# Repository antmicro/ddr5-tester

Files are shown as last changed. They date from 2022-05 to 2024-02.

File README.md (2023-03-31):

# Data Center RDIMM DDR5 Tester

Copyright (c) 2021-2023 [Antmicro](https://www.antmicro.com)



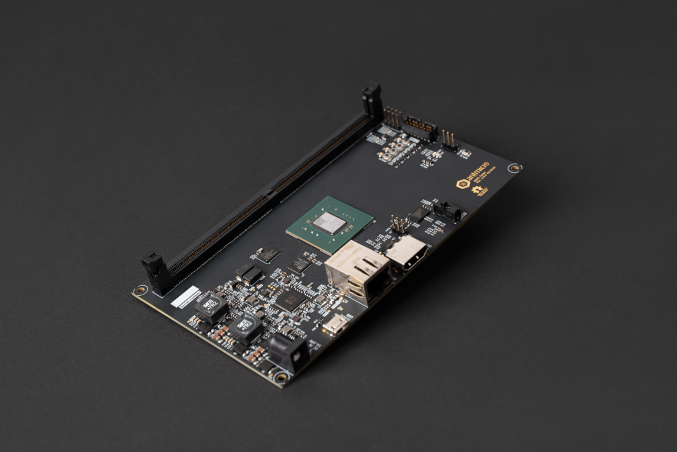
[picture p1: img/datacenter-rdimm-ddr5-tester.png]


## Overview

This project contains open hardware design files for an experimental platform built around Xilinx Kintex-7 FPGA.
The main purpose of this platform is to develop and customize RAM controllers supporting DIMM DDR5 RAM modules used in data centers.
The design files were prepared in KiCad.

## Project structure

The main directory contains KiCad PCB project files, a
LICENSE and README. The remaining files are stored in the following
directories:

-   `lib` - contains the component libraries
-   `img` - contains graphics for this README
-   `doc` - contains schematics and block diagrams

## Key Features

-   Kintex-7 FPGA - XC7K160T-2FBG676C
-   DDR5 DIMM connector
-   HDMI output connector
-   Ethernet RJ45 connector with 1GbE transciever
-   Micro USB debug connector with FT4232HQ FTDI USB controller
-   JTAG
-   microSD card slot
-   16 MBytes S25FL128S QSPI FLASH memory
-   S27KL0641 HyperRAM
-   External 7-12V power input
-   5 user LEDs
-   4 user buttons

## Block diagram

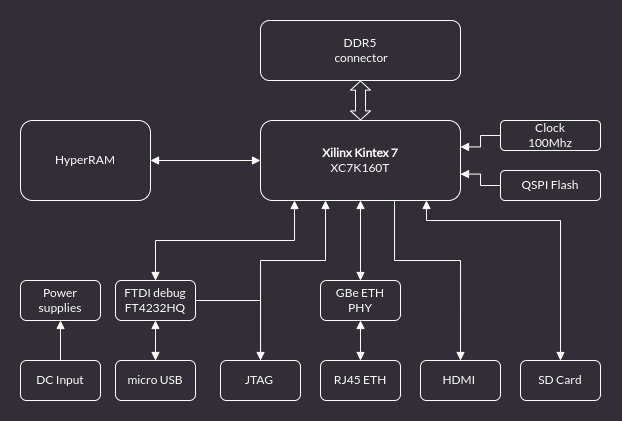
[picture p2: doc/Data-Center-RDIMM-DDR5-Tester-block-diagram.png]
Data Center RDIMM DDR5 Tester board diagram


## License

This project is published under the [Apache-2.0](LICENSE) license.

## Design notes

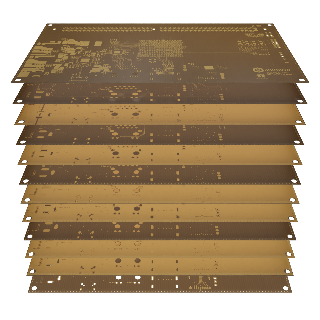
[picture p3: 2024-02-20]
assets/previews/layer1_thumbnail.webp

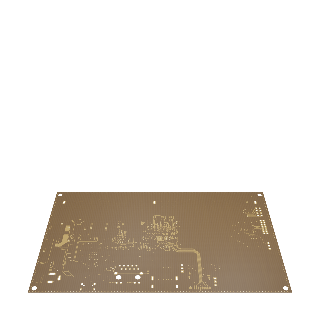
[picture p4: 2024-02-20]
assets/previews/layer12_thumbnail.png

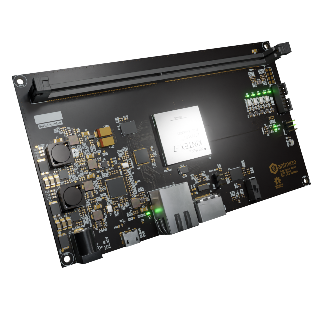
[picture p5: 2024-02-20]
assets/previews/leftT_thumbnail.png

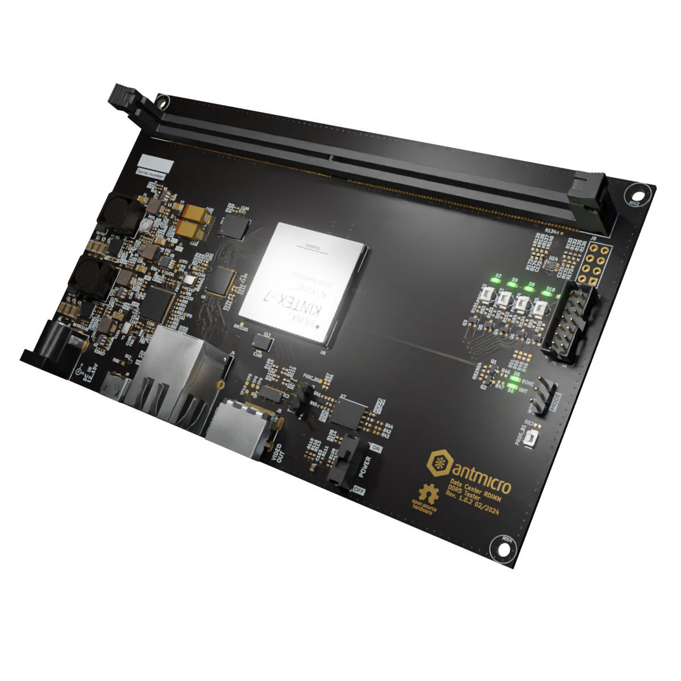
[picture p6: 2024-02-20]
assets/previews/rightT.webp

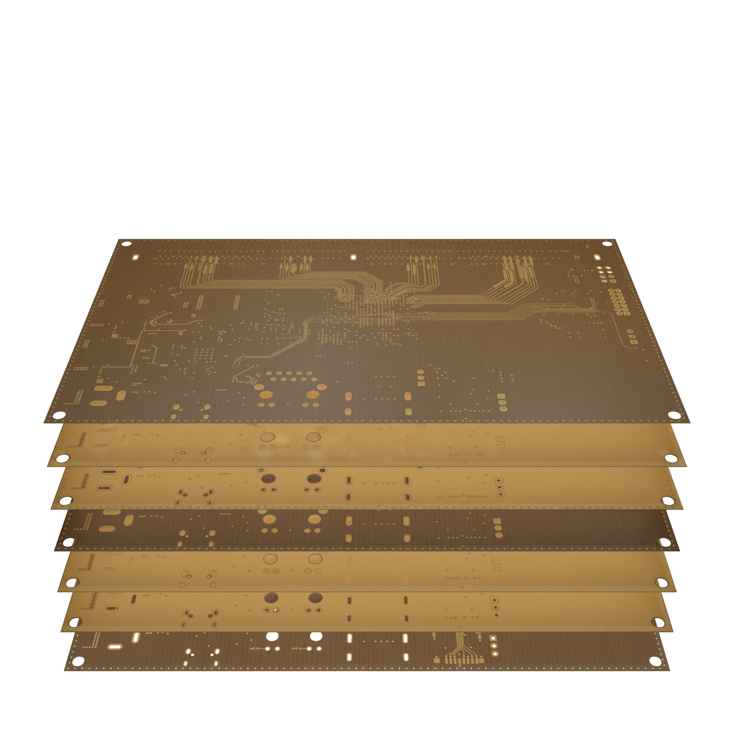
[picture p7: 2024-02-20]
assets/previews/layer6.png

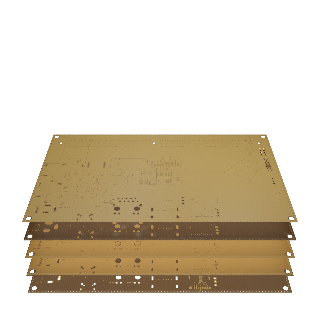
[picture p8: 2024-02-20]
assets/previews/layer8_thumbnail.png

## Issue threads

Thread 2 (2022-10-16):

Can't find Kintex-7 FPGA - XC7K100T-FBG686

StefanL312, 2022-10-16:
Hello,

Thank you for your work and for sharing this project.

I am currently working on my master thesis regarding DRAM row hammering and am interested in using your DDR5-tester.

I have trouble finding the XC7K100T-FBG686 FPGA.

Could you advise me on this matter. Would you have possibly meant the 160 variant instead?

I am looking forward to your reply.

Kind regards,
Stefan

pkatarzynski, 2022-12-07:
Hi Stefan - indeed there was a glitch in the MPN indicated in the README. I have already fixed that. The MPN for the FPGA should be XC7K160T-FBG676.  We are using XC7K160T-2FBG676C in the prototypes. The board can also be populated with 'FFG' version which is footprint-compatible.

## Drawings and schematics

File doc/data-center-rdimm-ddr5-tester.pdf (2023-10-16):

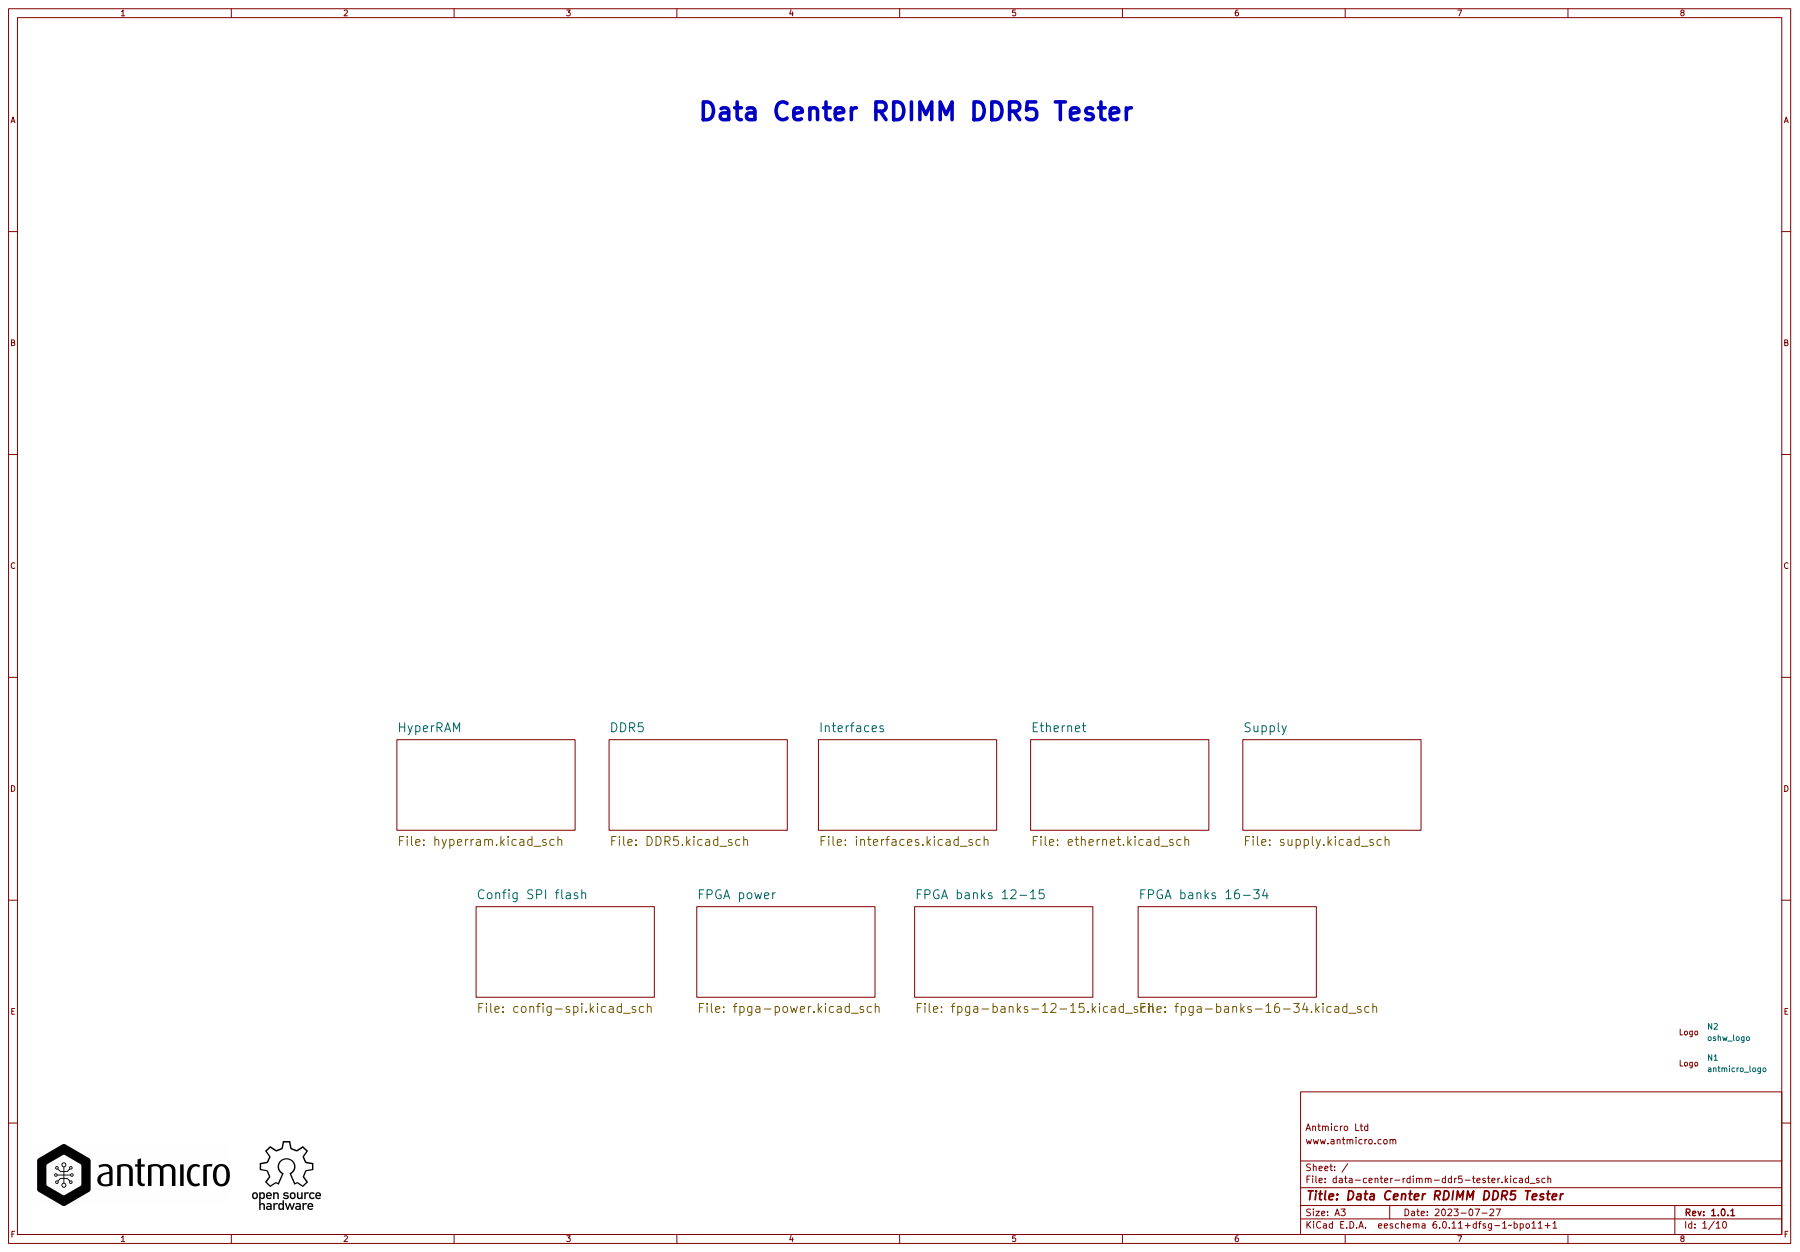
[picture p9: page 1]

Id: 1/10 Title: Data Center RDIMM DDR5 Tester File: data-center-rdimm-ddr5-tester.kicad_sch Sheet: / www.antmicro.com

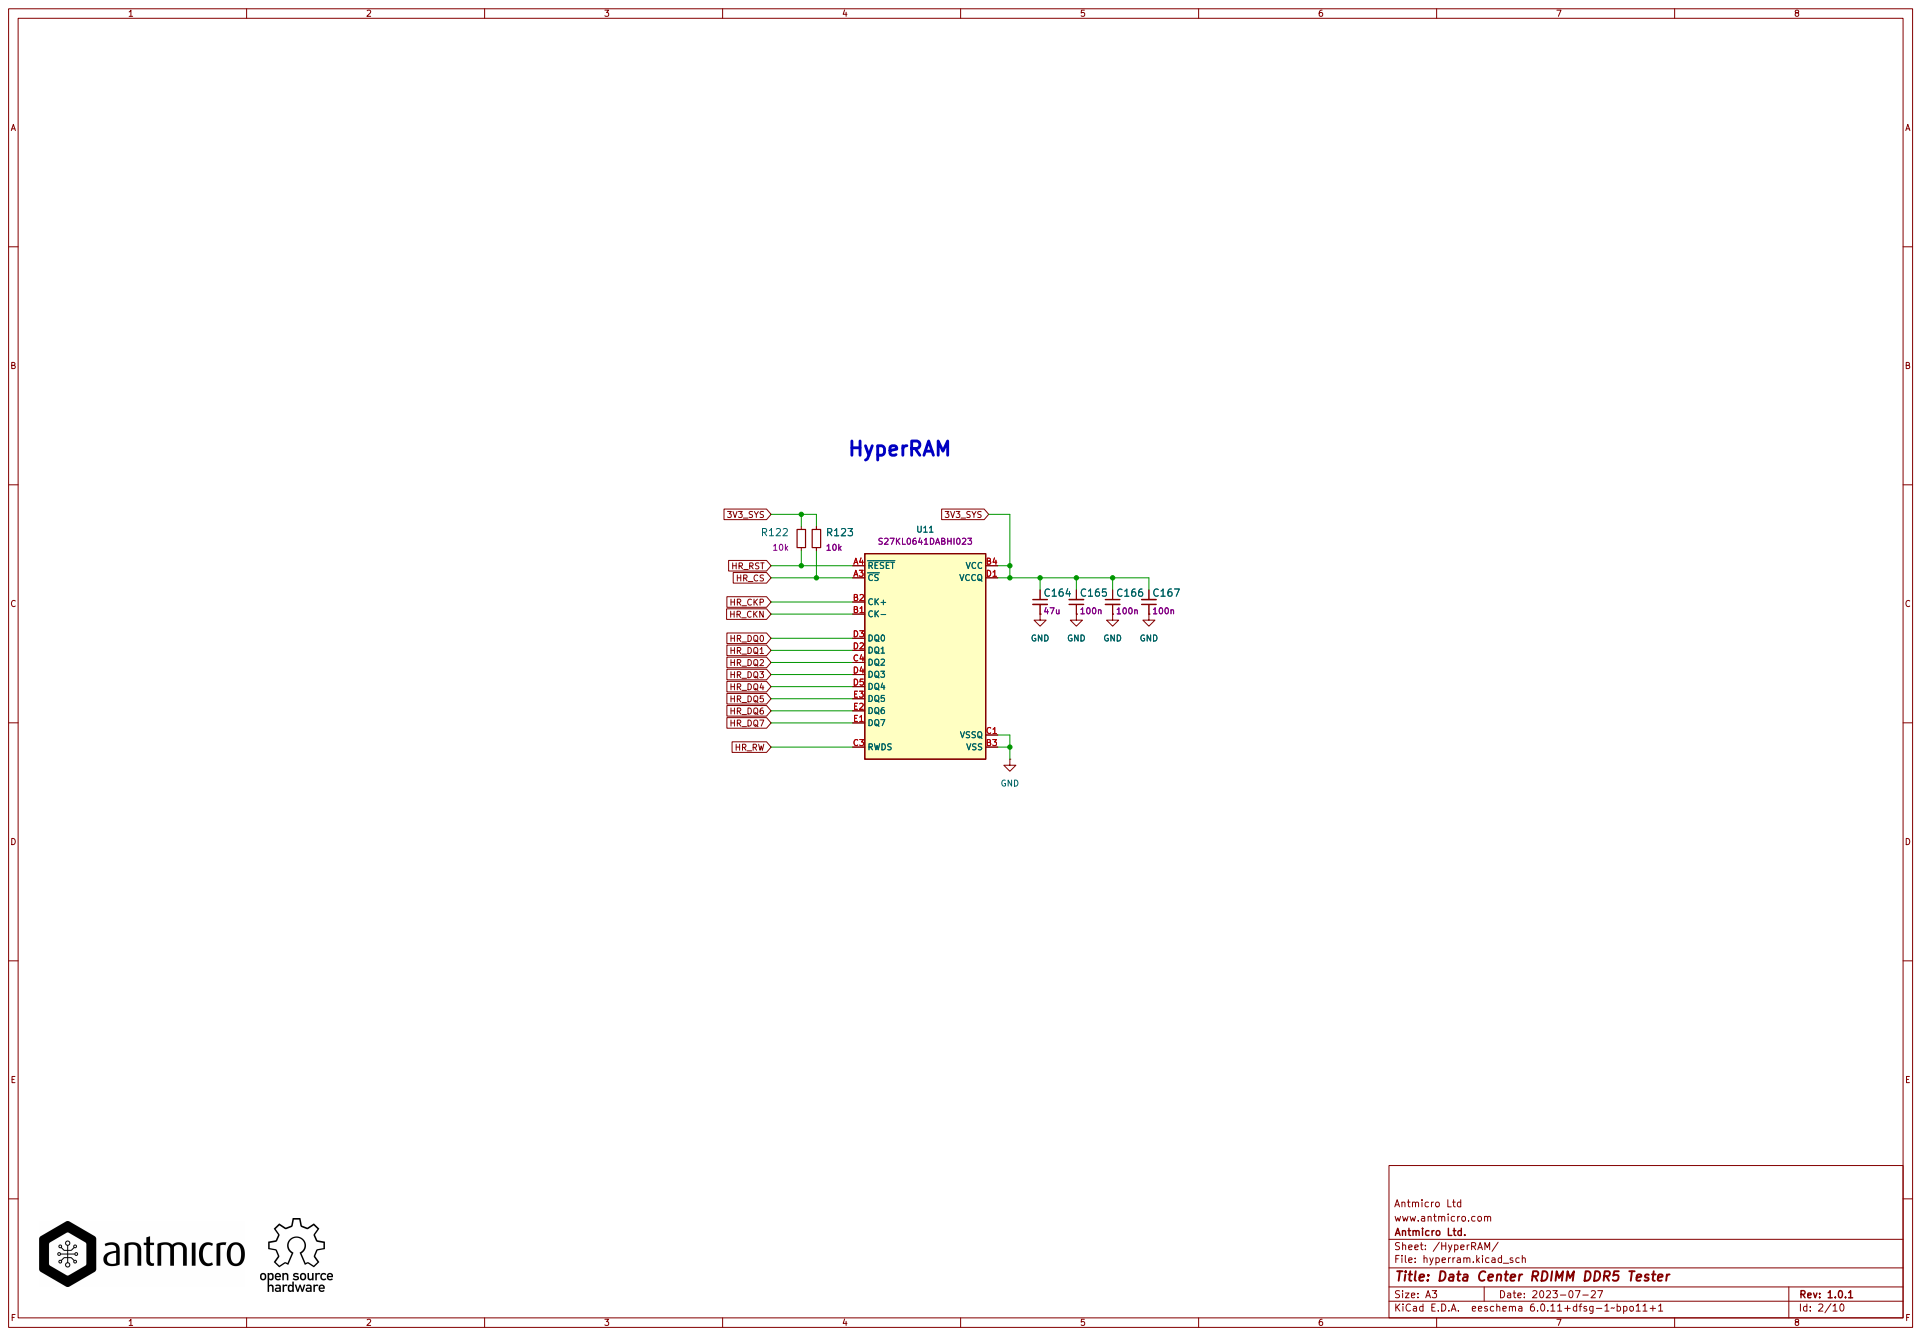
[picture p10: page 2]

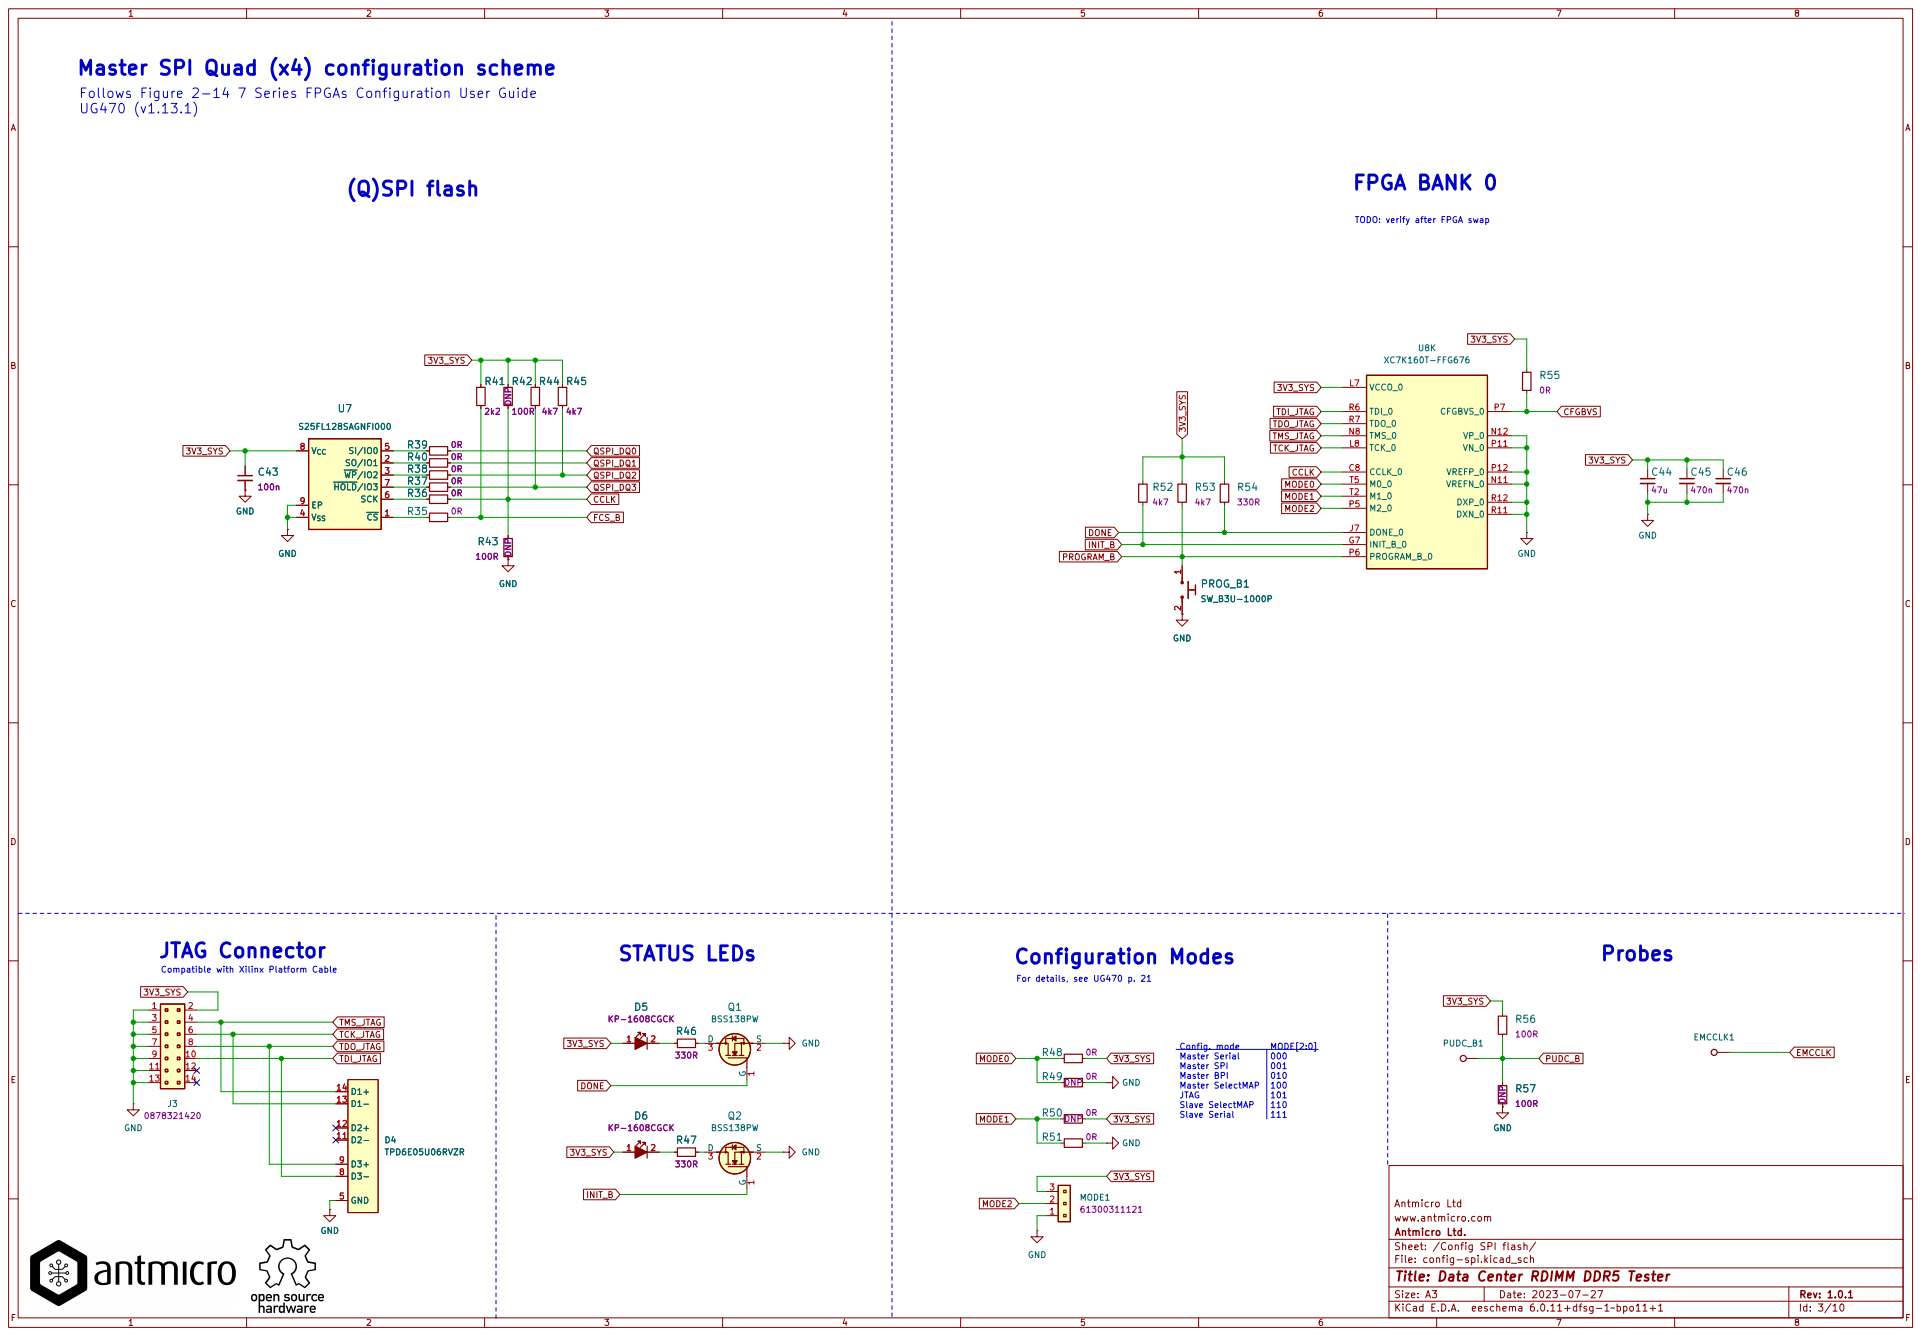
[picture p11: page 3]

Config. mode Master Serial Master SPI Master BPI Master SelectMAP

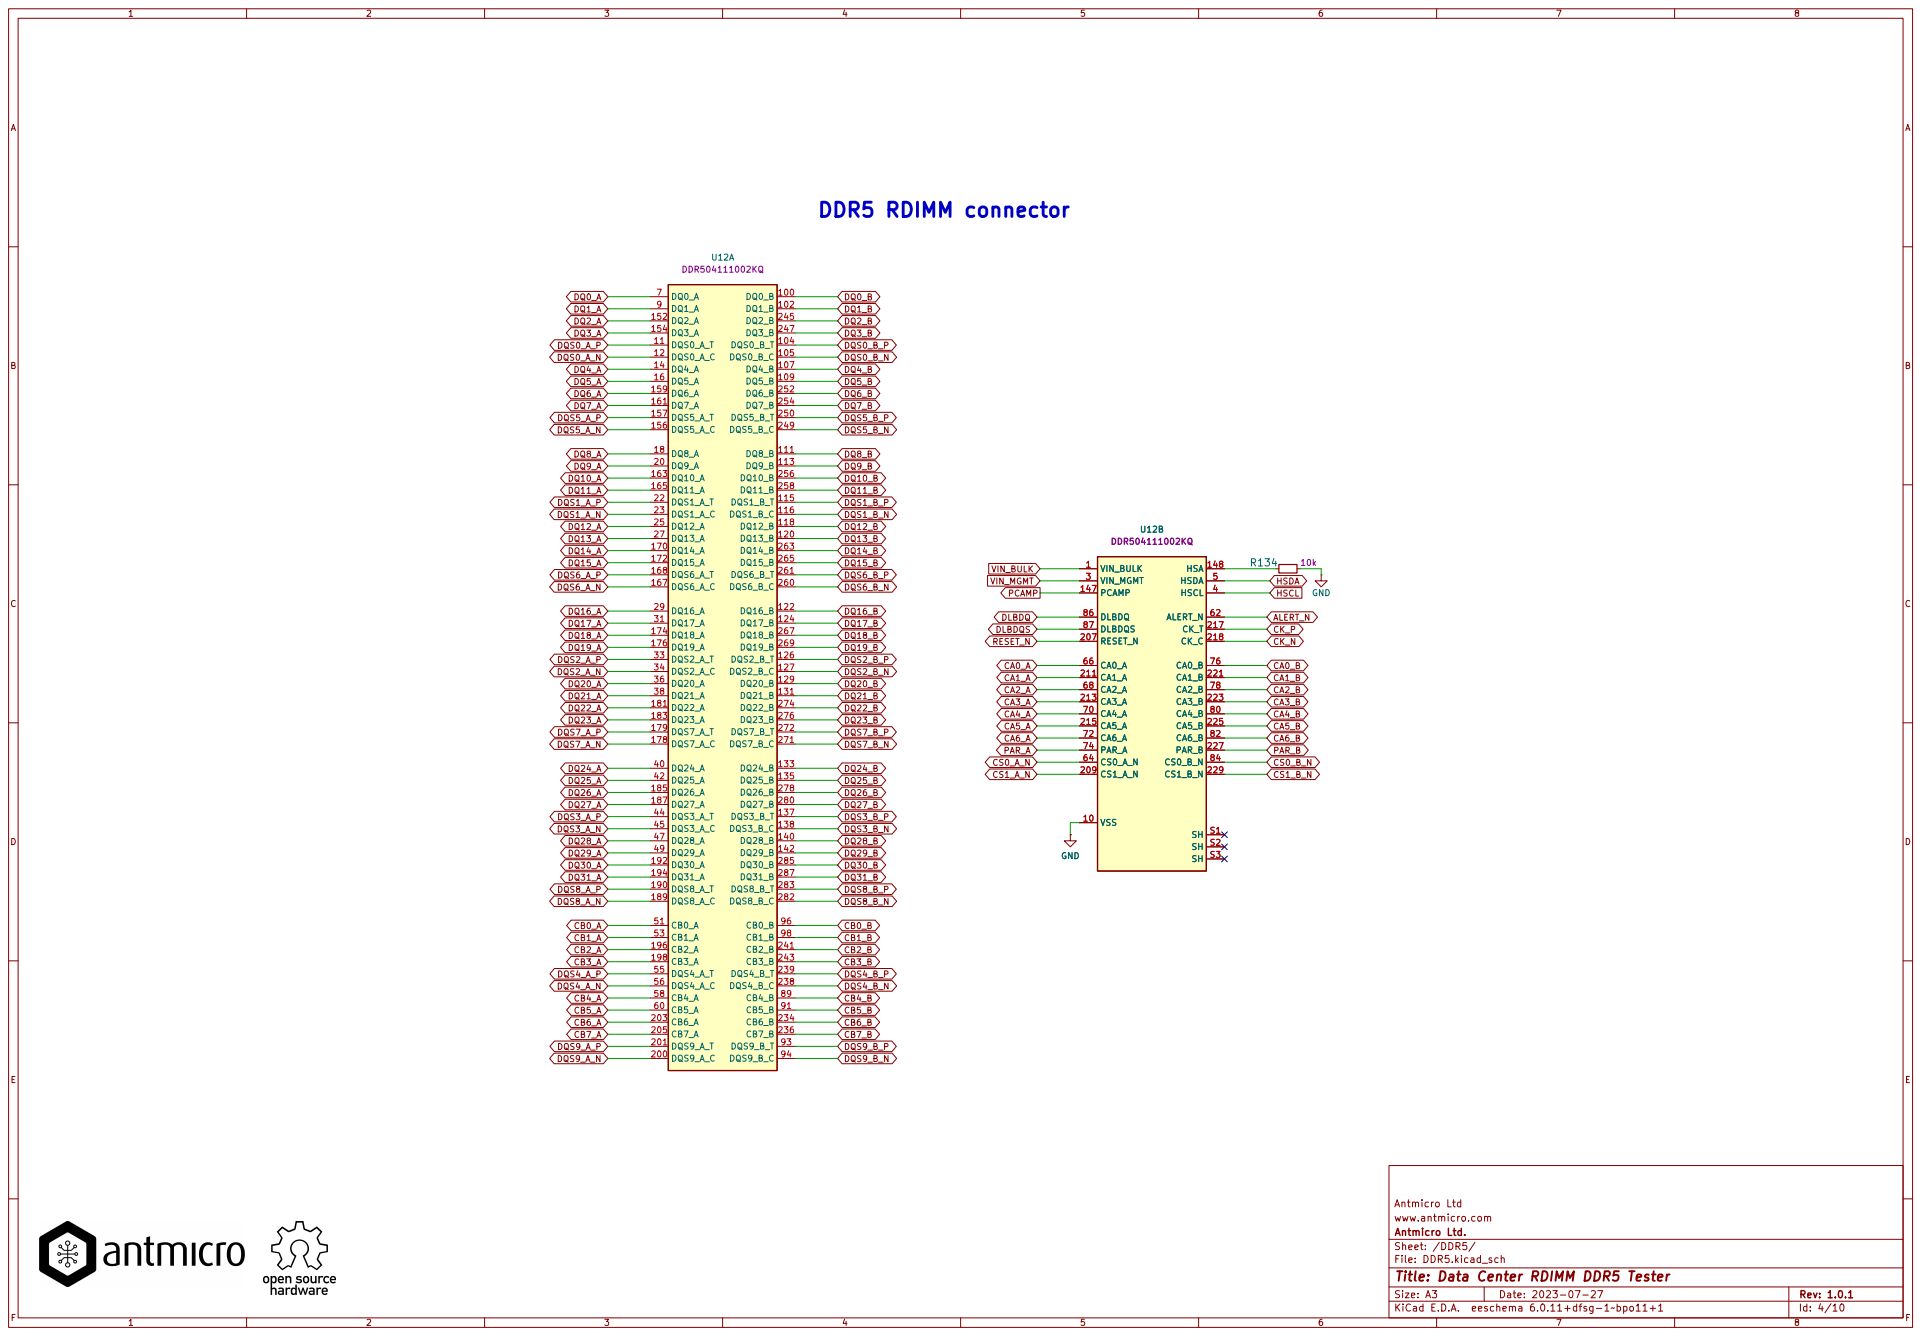
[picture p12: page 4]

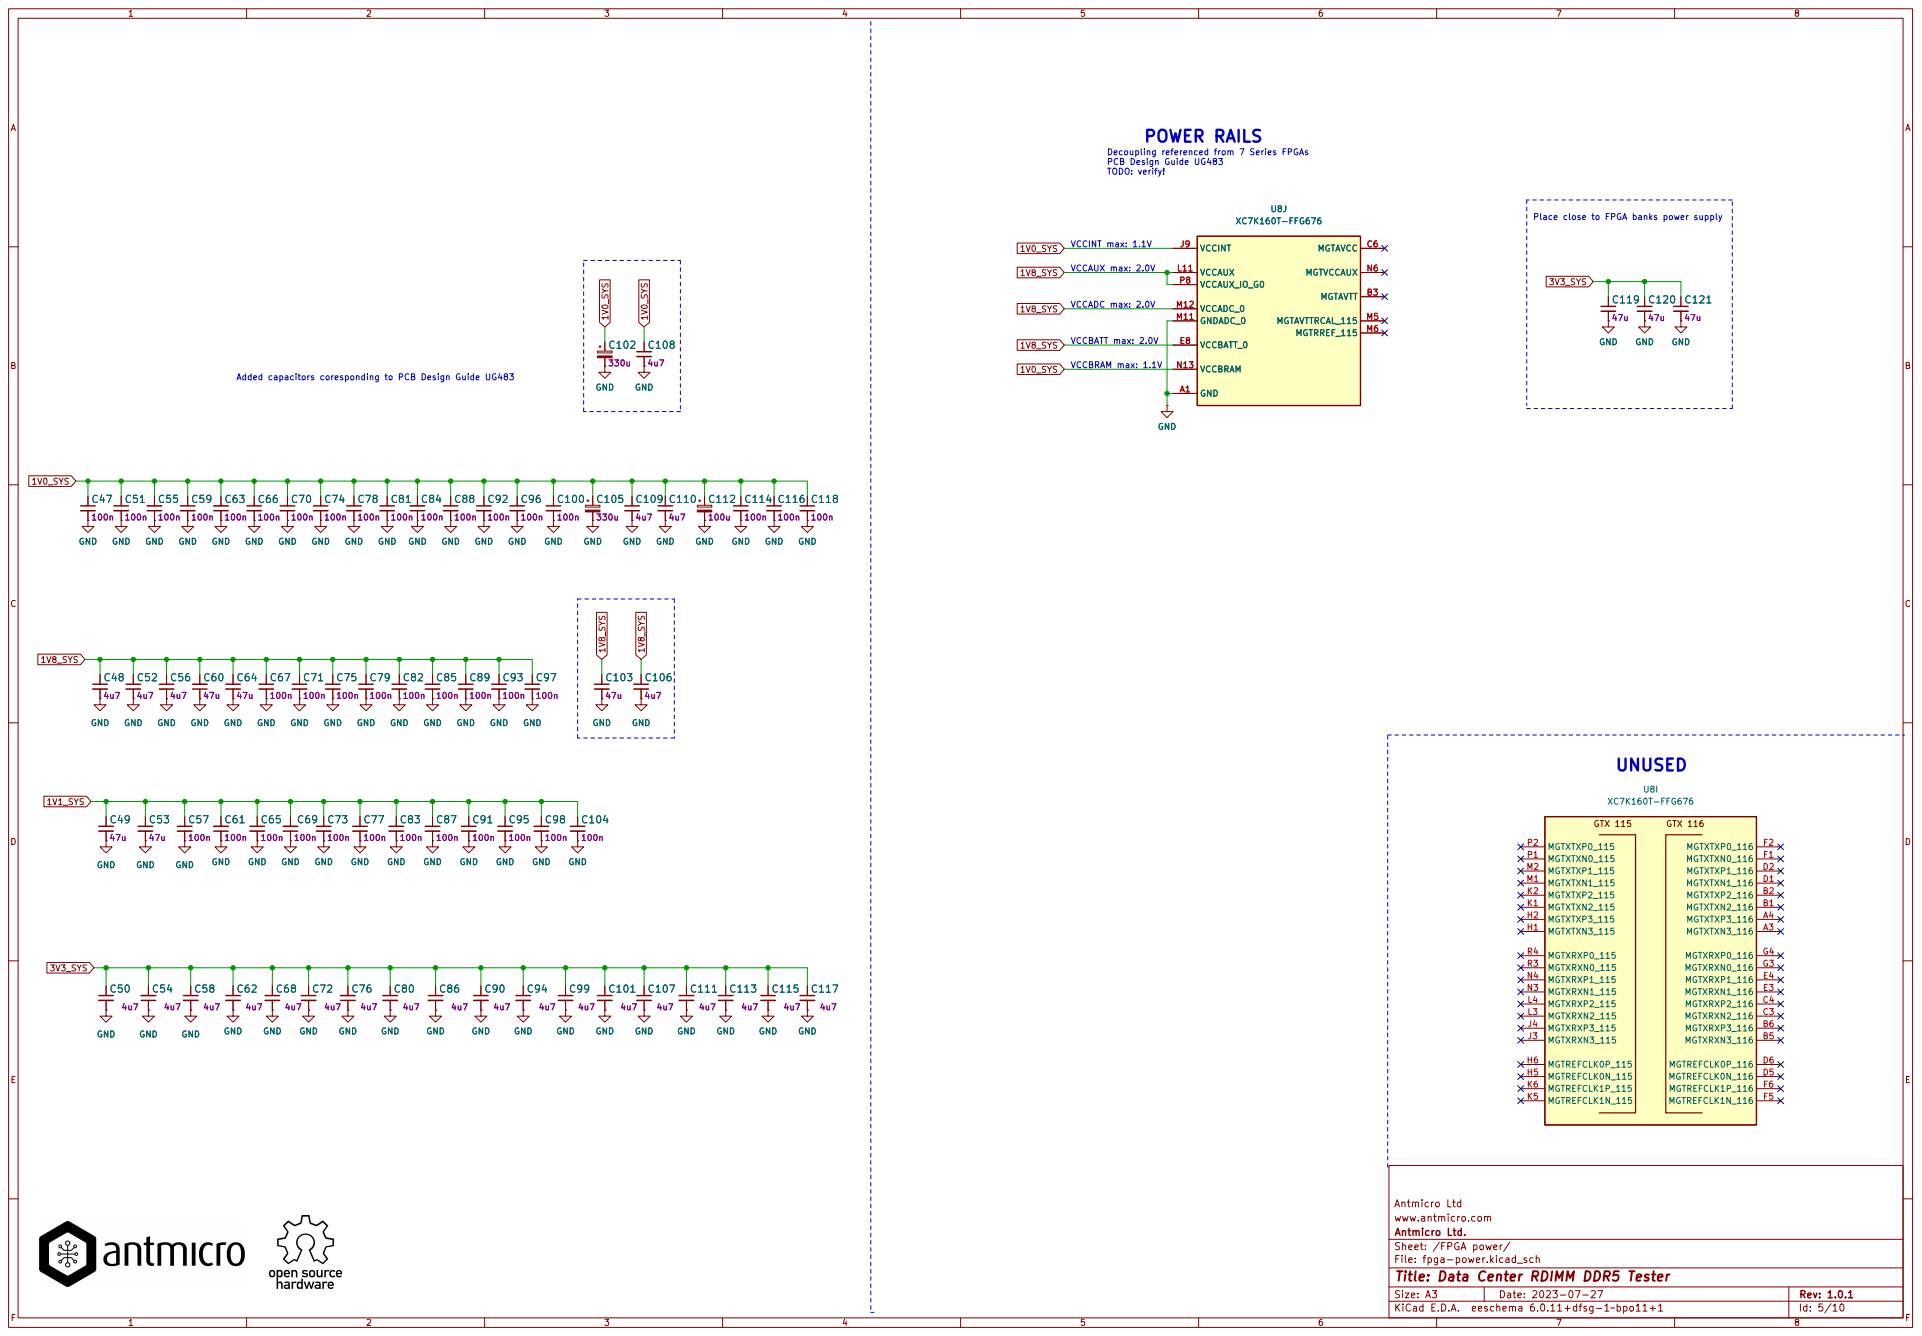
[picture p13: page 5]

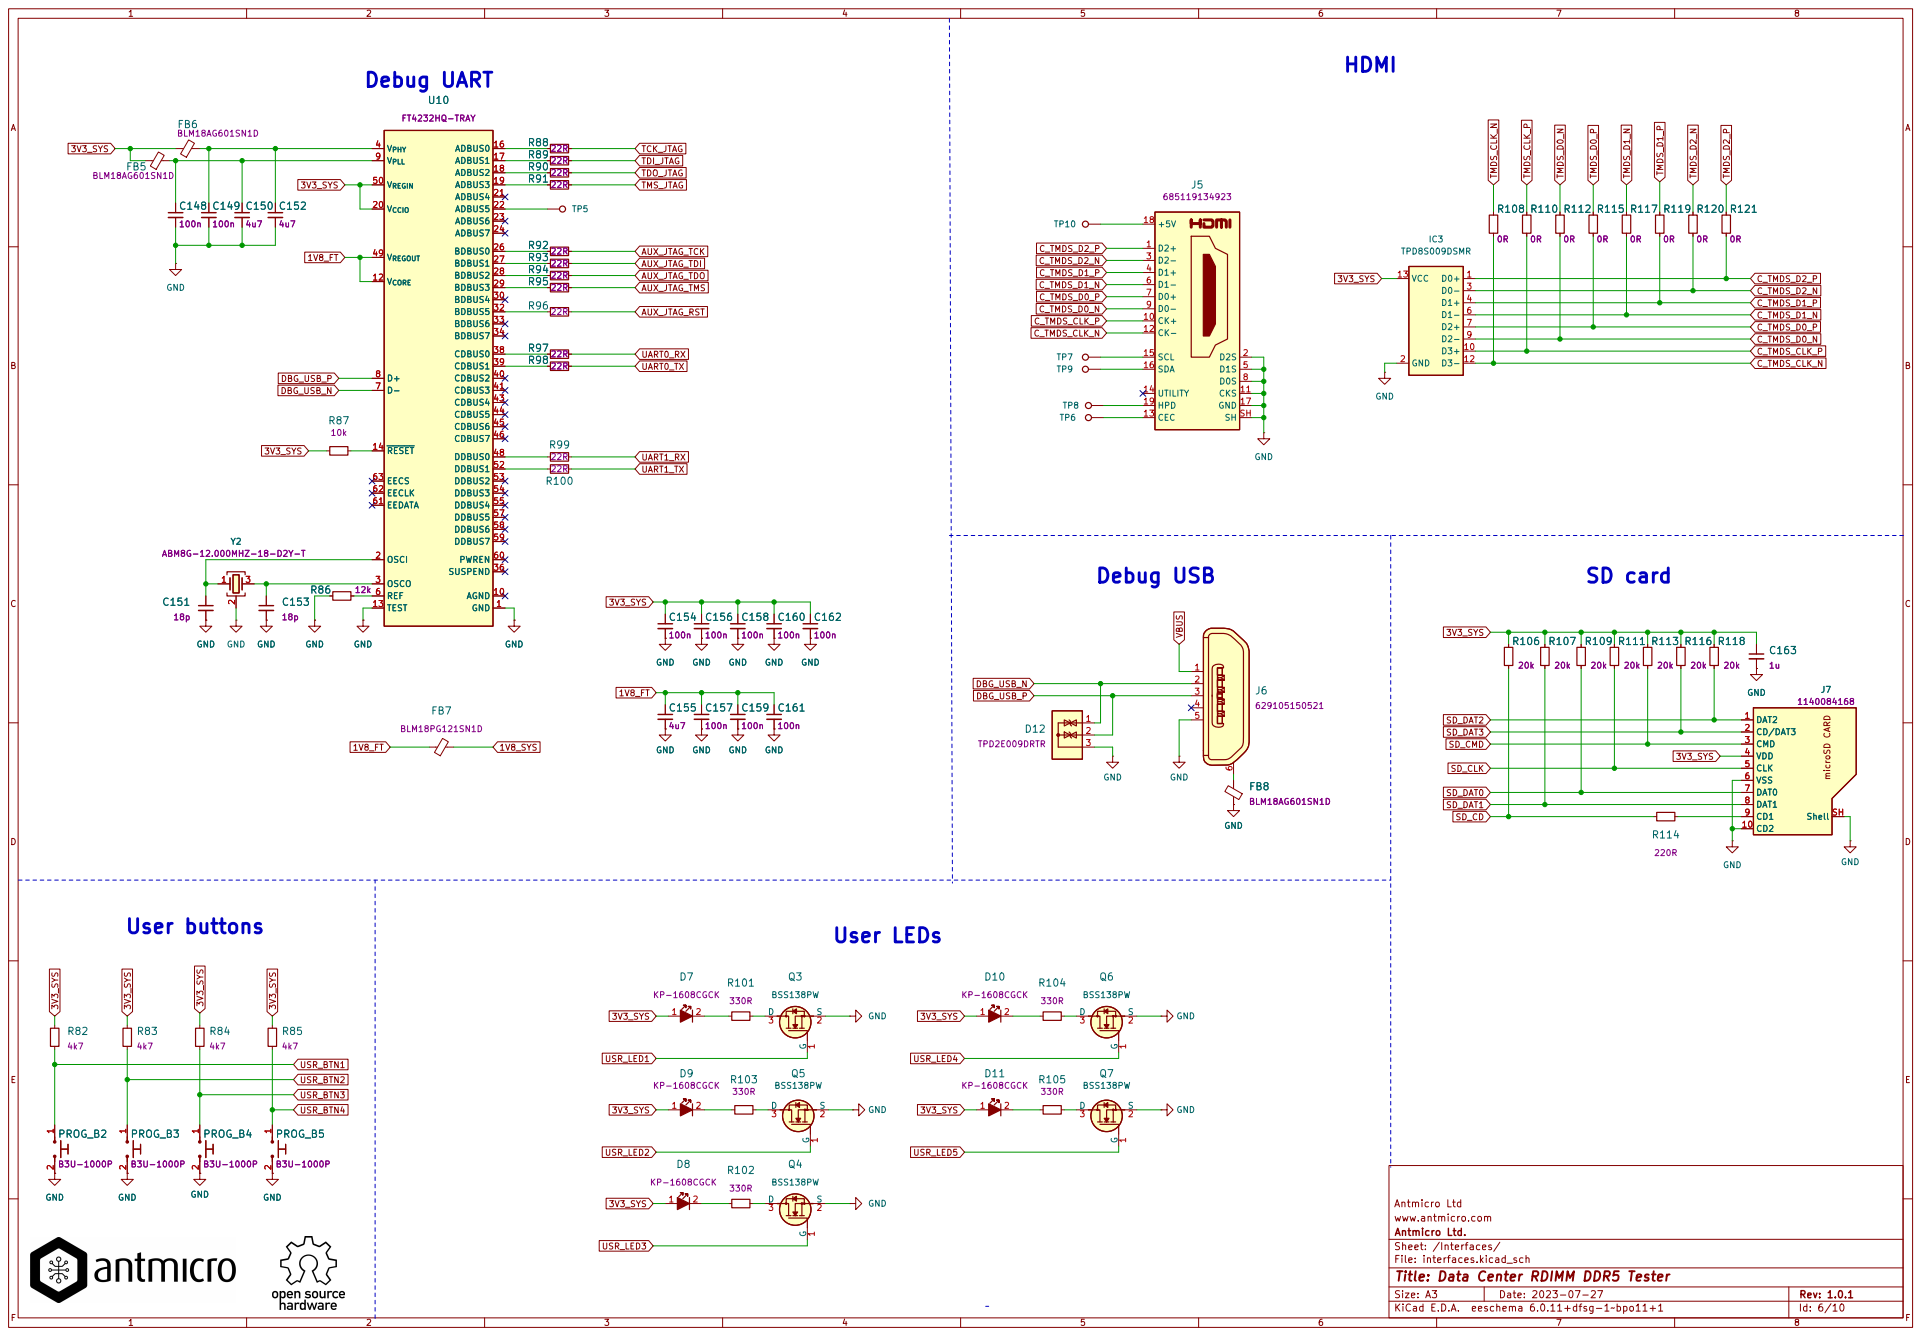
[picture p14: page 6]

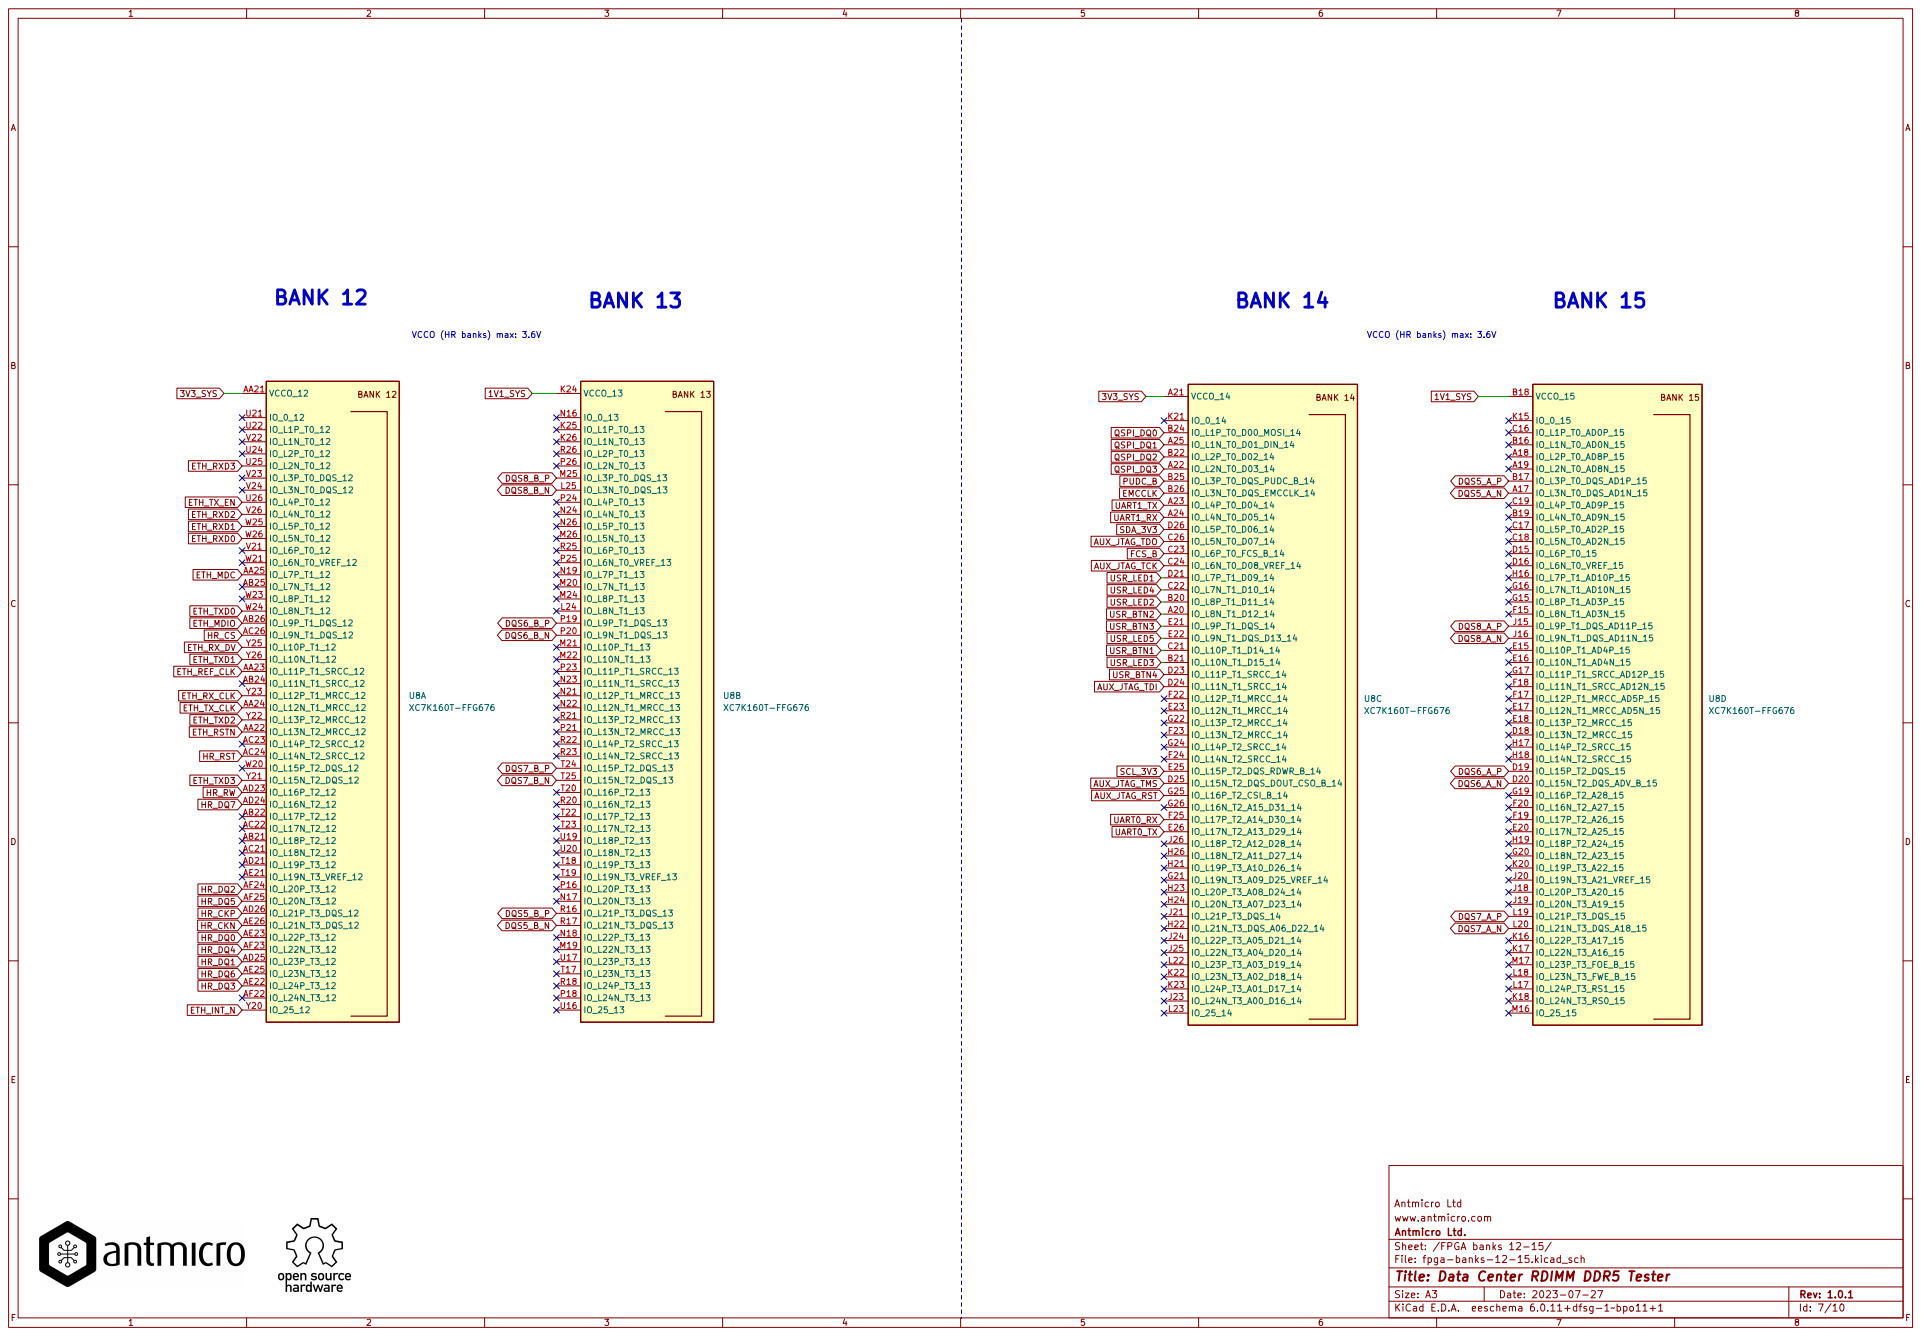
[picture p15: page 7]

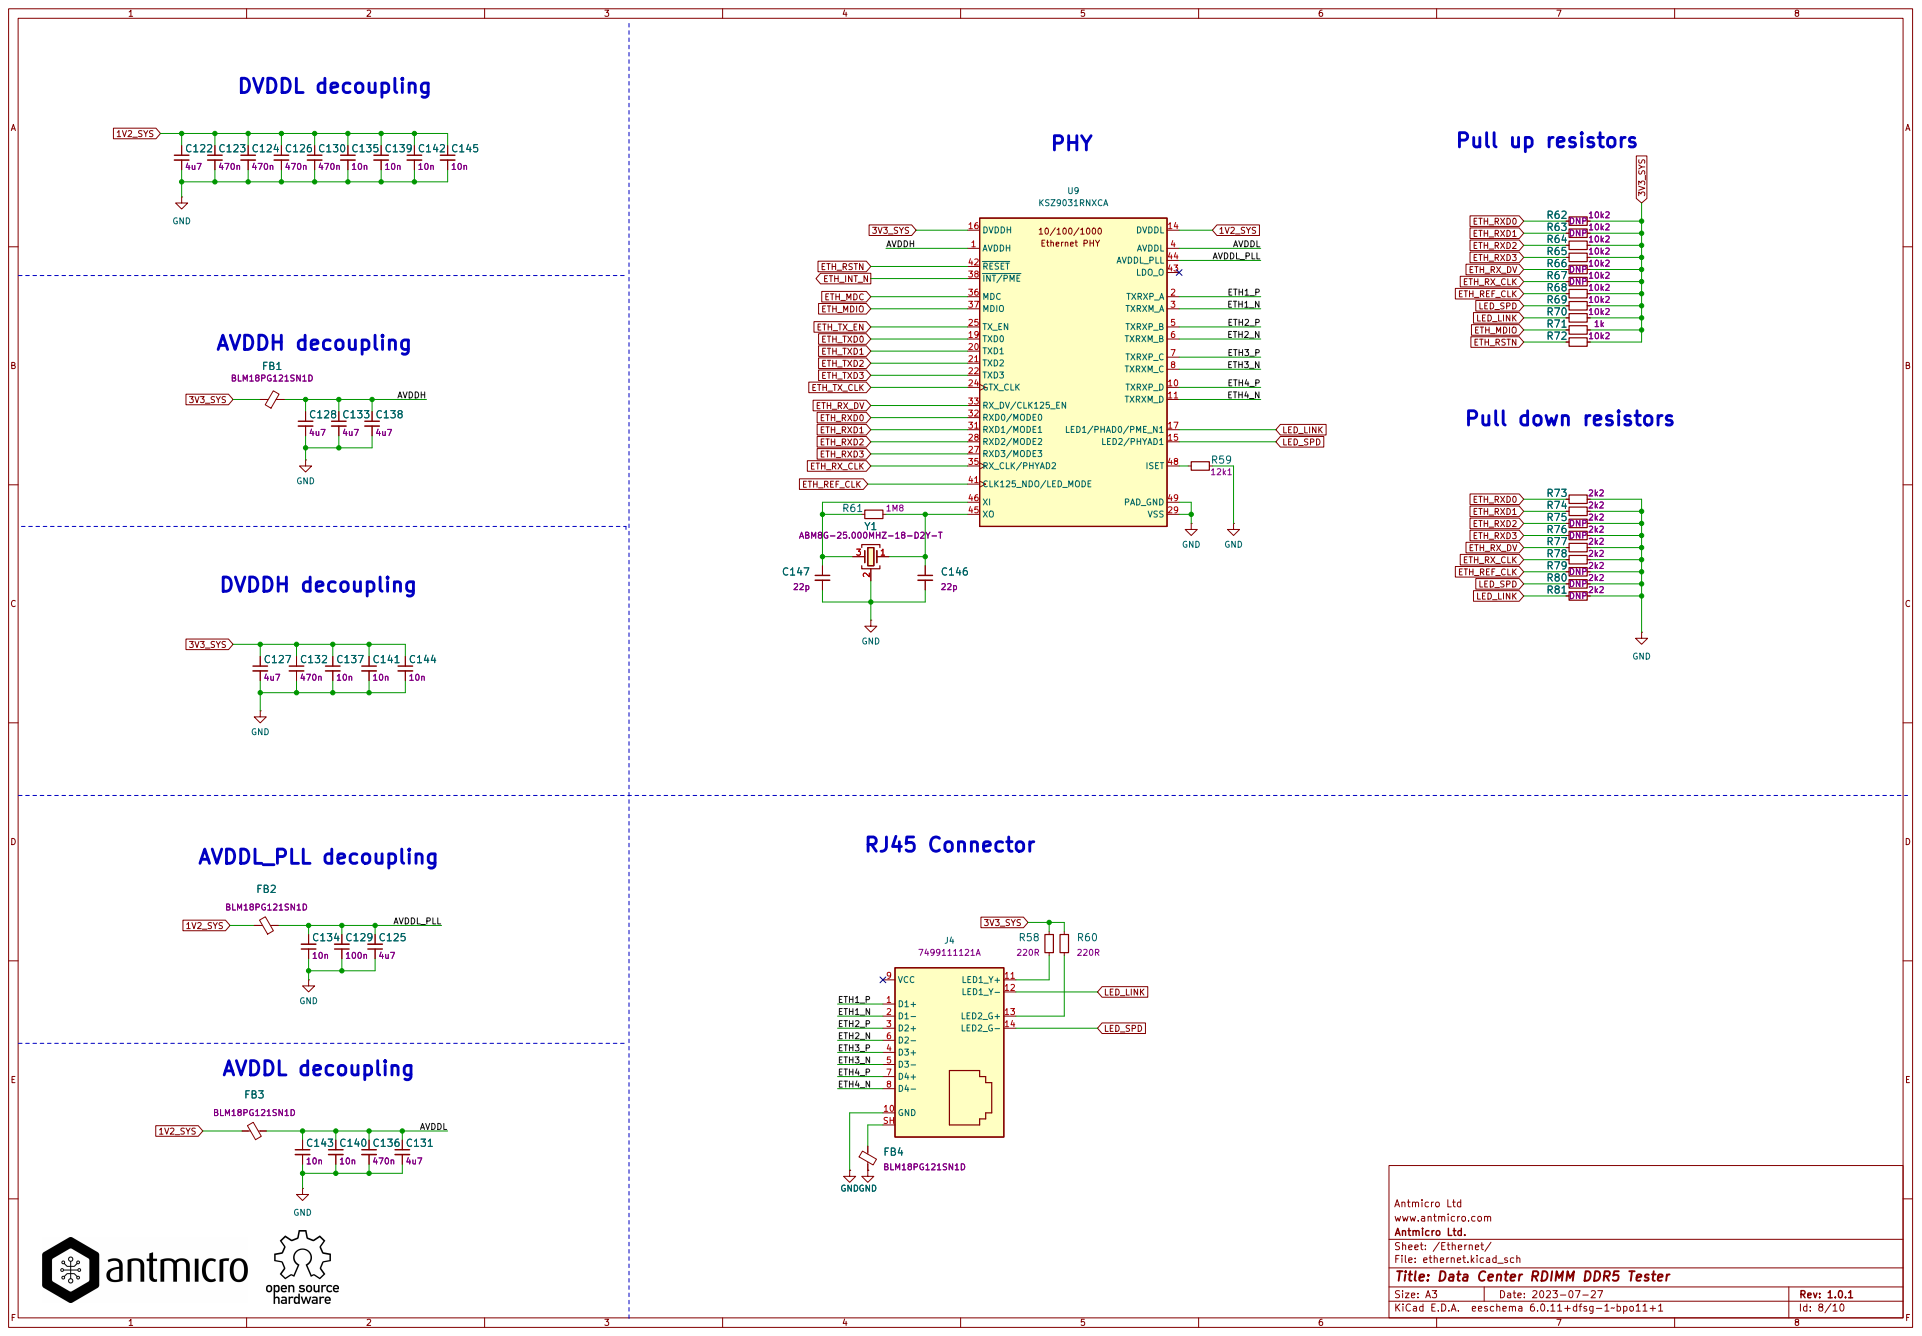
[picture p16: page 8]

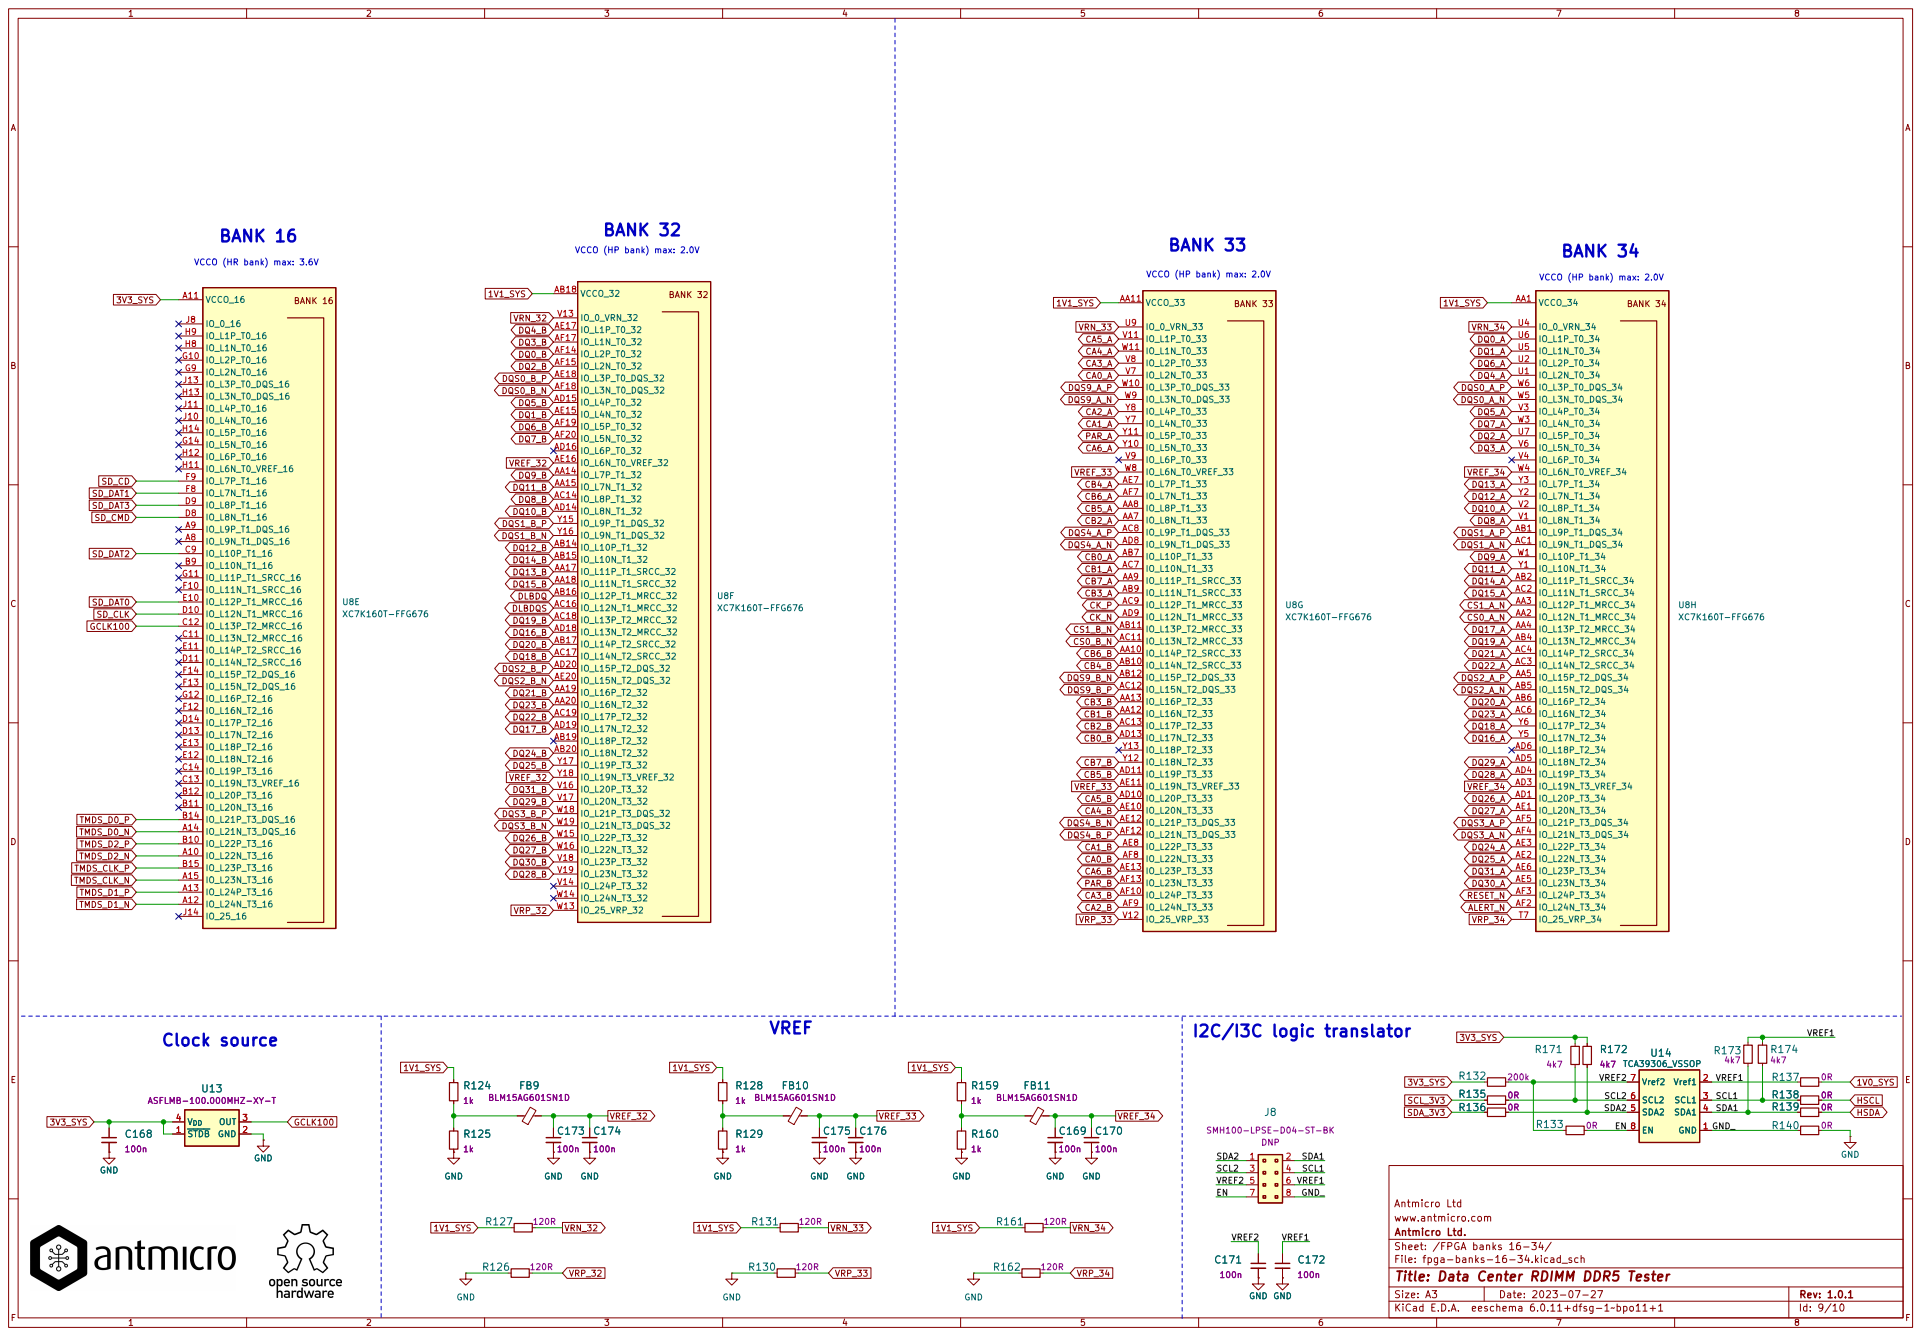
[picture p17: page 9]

VCCO (HR bank) max: 3.6V BANK 16

VCCO (HP bank) max: 2.0V BANK 33

VCCO (HP bank) max: 2.0V

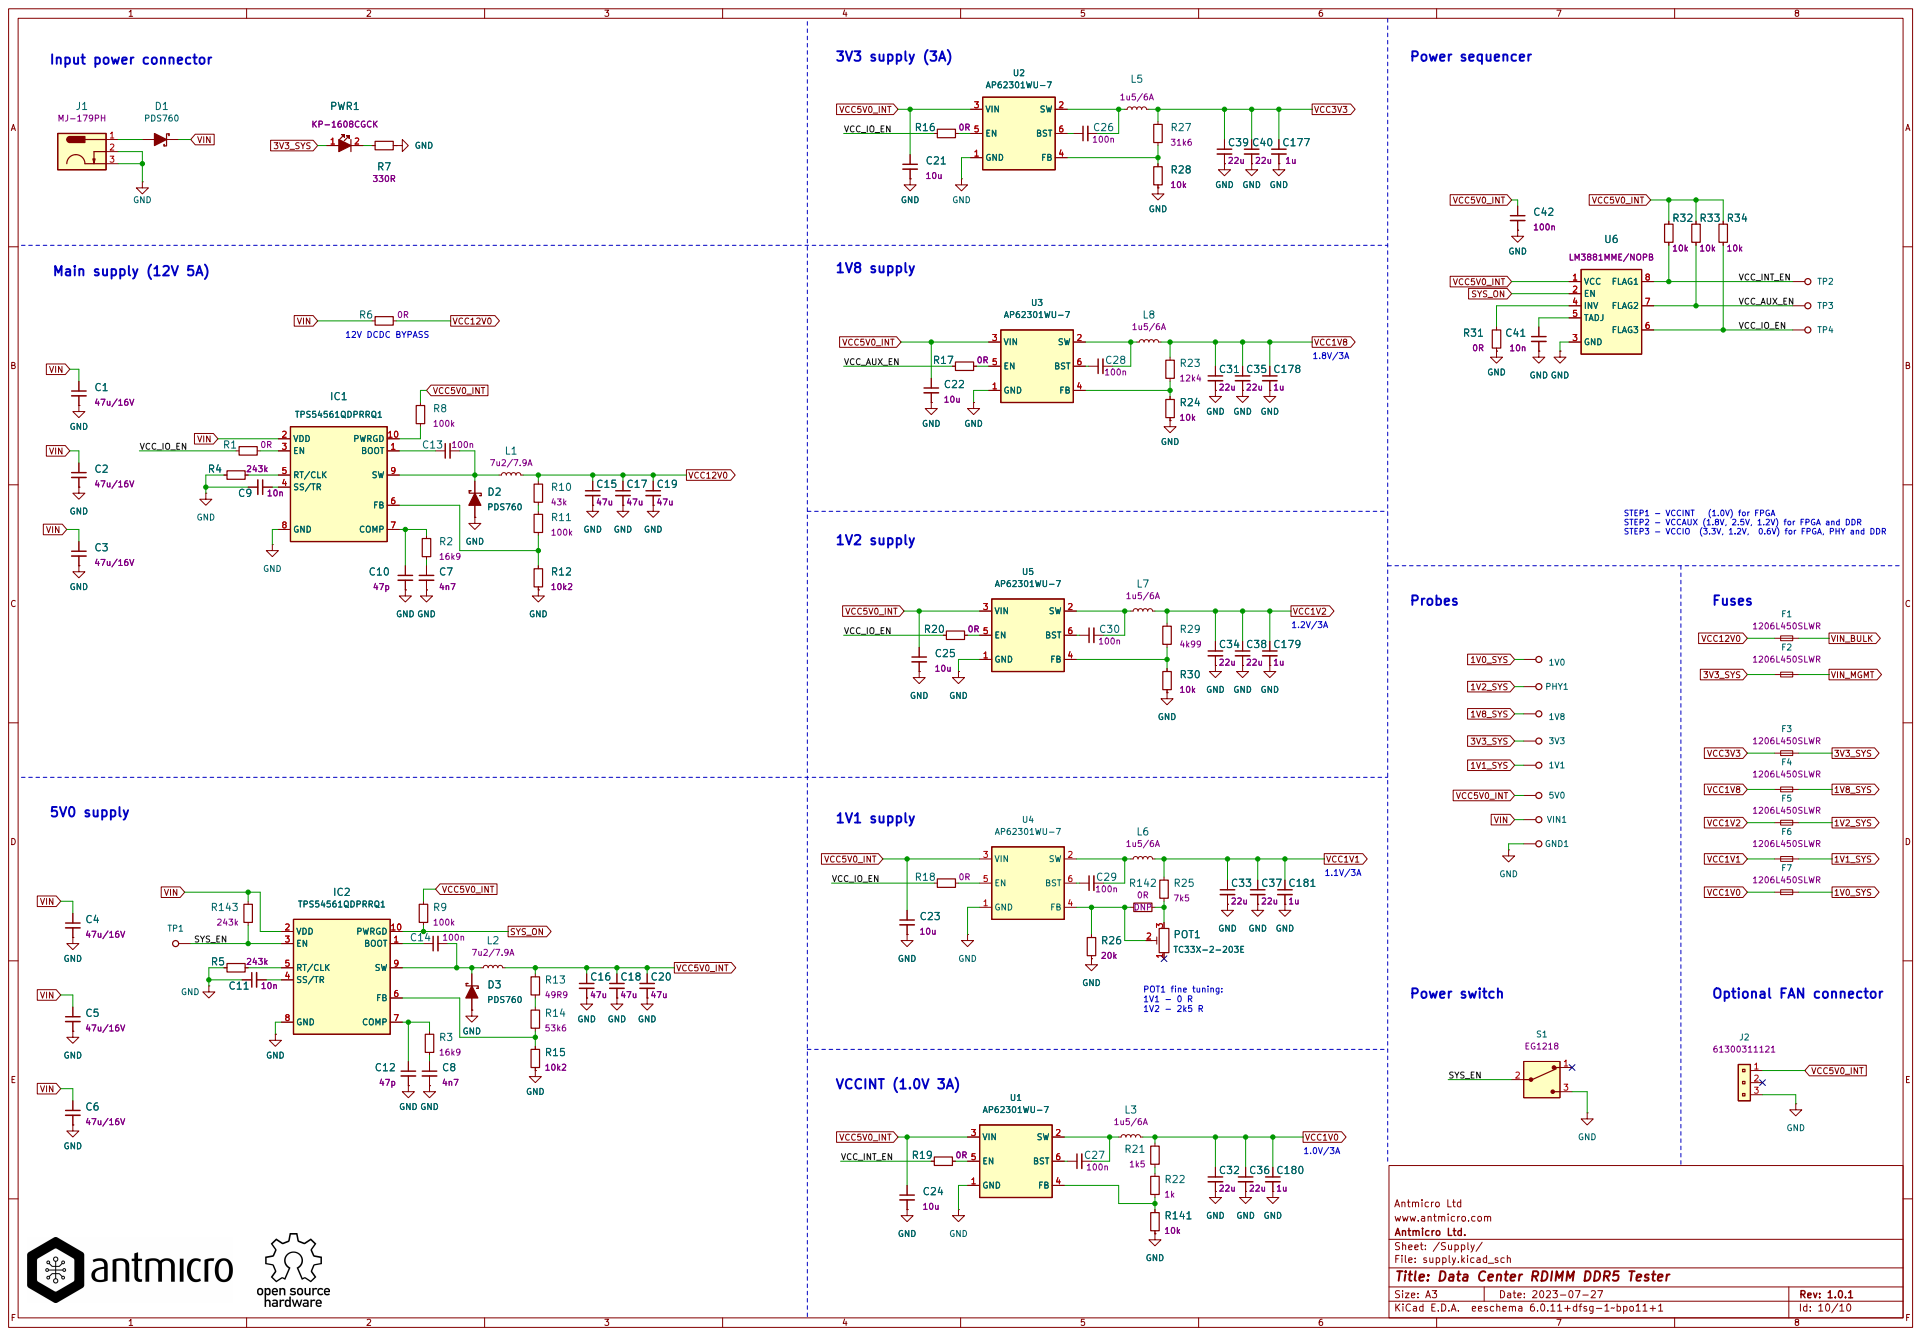
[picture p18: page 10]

STEP2 - VCCAUX (1.8V, 2.5V, 1.2V) for FPGA and DDR

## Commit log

2022-03-08 Inital commit
    [DDR4.sch, DDR5.sch, config-spi.sch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]
2022-03-08 Remove DDR4.sch
    [DDR4.sch]
2022-03-08 Add 1V1 supply
    [supply.sch]
2022-03-24 Add DDR5 DIMM connector, add DDR5 DIMM signal labels
    [DDR5.sch]
2022-03-24 Fix DQS4_A_P label
    [DDR5.sch]
2022-03-24 Placed DDR5 labels close to DDR4 signals that are going to be replaced 1:1
    [fpga-banks-12-15.sch, fpga-banks-16-34.sch]
2022-03-24 Connect remaining signals that do not require changing the pinout of the FPGA
    [fpga-banks-16-34.sch]
2022-03-24 Annotate DDR5 connector
    [DDR5.sch]
2022-03-24 Annotate 1V1 DC components
    [supply.sch]
2022-03-24 Connect remaining DQS signals, clear bank 16 for DDR5 use. Change HDMI and uSD connections
    [fpga-banks-12-15.sch, fpga-banks-16-34.sch]
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2022-03-24 Connect remaining singnals from DDR5
    [fpga-banks-16-34.sch]
2022-03-24 Update local libraries
    [DDR5.sch]
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2022-03-24 Update input power label for banks 12-15,16-34
    [fpga-banks-12-15.sch, fpga-banks-16-34.sch]
2022-03-24 Update power labels
    [supply.sch]
2022-03-24 Add 12V DCDC, rearrange schematic
    [supply.sch]
2022-03-24 Supply cleanup
    [supply.sch]
2022-03-24 Clean supply sch, add 1V1 trimm pot add 12V bypass, loclib
    [supply.sch]
2022-03-24 Annotate parts in supply.sch
    [supply.sch]
2022-03-24 Move GCLK100 to MRCC pin
    [fpga-banks-12-15.sch]
2022-03-24 Change capacitors in power domains after changing bank voltages
    [fpga-power.sch]
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2022-03-24 Add 10uF cap to 3V3 DCDC output
    [supply.sch]
2022-03-24 Change packages of some passives. Unify parts where is is possible
    [supply.sch]
2022-03-24 Update voltage labels
    [fpga-banks-16-34.sch]
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2022-03-24 Update 43K resistor, change 12V DCDC EN signal input
    [supply.sch]
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2022-03-24 Add 1V1 test point, power supply layout
    [supply.sch]
2022-03-24 Reannotate parts, label placement
    [DDR5.sch, config-spi.sch, data-center-ddr5-tester.sch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]
2022-03-24 Remove DDR4 related labels connected to FPGA
    [fpga-banks-12-15.sch, fpga-banks-16-34.sch]
2022-03-24 Change 1V1 trimming circuitry
    [supply.sch]
2022-03-24 Remove comment
    [DDR5.sch]
2022-03-24 DDR5 basic connection to FPGA
    [fpga-banks-12-15.sch, fpga-banks-16-34.sch]
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2022-03-24 Update naming convention
    [DDR5.sch, config-spi.sch, data-center-ddr5-tester.sch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]
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2022-03-25 Improve DDR5 pinout, add Vref, Vrn and Vrp circuitry for all DDR related banks
    [fpga-banks-12-15.sch, fpga-banks-16-34.sch]
2022-03-25 Change pinout to match DDR4 test board
    [fpga-banks-12-15.sch, fpga-banks-16-34.sch]
2022-03-25 Remove unused no-connect flags
    [fpga-banks-12-15.sch]
2022-03-25 Add no-connect to unused pins
    [fpga-banks-12-15.sch]
2022-03-25 Move TMDS signals to match DDR4
    [fpga-banks-16-34.sch]
2022-03-25 Update power labels on capacitors from bank 16
    [fpga-power.sch]
2022-03-25 Enumerate parts
    [fpga-banks-16-34.sch]
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2022-03-28 DDR5 fanout, fix DDR5 connector footprint
2022-03-28 Route first and second dimm signals, adjust pinout for easier routing
    [fpga-banks-16-34.sch]
2022-03-28 Reute third dimm signals
    [fpga-banks-16-34.sch]
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2022-03-29 Route third set of DQ/DQS
    [fpga-banks-16-34.sch]
2022-03-29 Route CA_A signals
    [fpga-banks-16-34.sch]
2022-03-29 Swap CA_A and CA_B pins, route CB_A signals
    [fpga-banks-16-34.sch]
2022-03-30 Route CA_A, CA_B and two DQ/DQS signals groups
    [fpga-banks-16-34.sch]
2022-03-30 Route CB_B signals, adjust pinout
    [fpga-banks-16-34.sch]
2022-03-30 Change layer of DQS4 and adjacent singals, route CK singal
    [fpga-banks-16-34.sch]
2022-03-31 Route CB_B signals, improve CA_B singals routing
    [fpga-banks-16-34.sch]
2022-03-31 Route remaining DDR5 signals
    [fpga-banks-12-15.sch, fpga-banks-16-34.sch]
2022-03-31 Connect all remaining items
    [fpga-banks-16-34.sch]
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2022-04-04 Add 10K resistor between HSA and GND
    [DDR5.sch]
2022-04-04 Replace I2C tranlator with I3C compatible, adjust shcematic and PCB
    [fpga-banks-16-34.sch]
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2022-04-04 Fix gaps in power planes under DQ/DQS signals
    [fpga-banks-12-15.sch]
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2022-04-05 Fix R29 value
    [supply.sch]
2022-04-05 Change vias from F.Cu to In7.Cu and F.Cu to In9.Cu to through hole, adjust PCB to changes
2022-04-05 Add 0R resistors and breakout pins to I3C translator IC
    [fpga-banks-16-34.sch]
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2022-04-06 Rename kicad project
    [DDR5.sch, config-spi.sch, data-center-ddr5-tester.sch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]
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2022-04-08 Proposed layout of exchanged 3V3 buck converter to AP62301WU-7
    [supply.sch]
2022-04-08 Finished proposed layout of all 5 buck converters exchanged to AP62301WU-7
    [supply.sch]
2022-04-11 Added info on sch about POT1 values and output voltage. DCDC converters' placement adjusted to fit designators
    [supply.sch]
2022-04-11 Finished layout of exchanged DCDC converters
    [supply.sch]
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2022-04-19 Mention AP62301WU-7 swap
    [ddr5-testboard-BOM-sourcing.csv]
2022-07-14 Fix I2C pullup issue. Migrate project to KiCad 6
    [DDR5.kicad_sch, config-spi.kicad_sch, ddr5-testboard.kicad_sch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]
2022-07-14 Remove KiCad 5 files
    [DDR5.sch, config-spi.sch, ddr5-testboard.sch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]
2022-07-18 Added EN pullup for TPS54561 to avoid disabling by touch
    [DDR5.kicad_sch, config-spi.kicad_sch, ddr5-testboard.kicad_sch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]
2022-12-07 Update project libraries
    [ddr5-testboard.kicad_sch, supply.kicad_sch]
2023-02-24 Update FPGA footprint reference
    [config-spi.kicad_sch, ddr5-testboard.kicad_sch, fpga-banks-12-15.kicad_sch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]
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2023-03-30 Update naming on the front page
    [data-center-rdimm-ddr5-tester.kicad_sch]
2023-10-13 Introduce component standarization
    [DDR5.kicad_sch, config-spi.kicad_sch, data-center-rdimm-ddr5-tester.kicad_sch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]
2023-10-16 Add OHP assets
    [stackup.csv]
2024-02-20 [#55296] component update
    [DDR5.kicad_sch, config-spi.kicad_sch, data-center-rdimm-ddr5-tester.kicad_sch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]
